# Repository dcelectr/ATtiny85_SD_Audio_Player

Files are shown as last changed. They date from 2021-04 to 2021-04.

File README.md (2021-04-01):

# ATtiny85_SD_Audio_Player
Based on [Simple SD Audio Player](http://elm-chan.org/works/sd8p/report.html)
High voltage serial programer is needed to set the RSTDISBL fuse for the ATiny SD Audio Player (Stereo, OSC, and Mono-HR versions).
You may used the [ProMini HVSP](https://github.com/dcelectr/ProMini_HVSP/tree/main)

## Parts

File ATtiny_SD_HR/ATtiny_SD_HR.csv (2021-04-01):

Reference | Quantity | Value | Footprint | Datasheet | P/N
C1 C3 | 2 | 100nF | Capacitor_SMD:C_0805_2012Metric_Pad1.18x1.45mm_HandSolder | ~ | 885012207011
C2 C5 | 2 | 100uF | Capacitor_Tantalum_SMD:CP_EIA-3216-10_Kemet-I_Pad1.58x1.35mm_HandSolder | ~ | TPSC107M016R0200
J1 | 1 | Micro_SD_Card_Det | User_PCB_Libraries:Molex_1051620001_KiCad | https://www.hirose.com/product/en/download_file/key_name/DM3/category/Catalog/doc_file_id/49662/?item_id=195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 | 1051620001
J2 J3 J4 | 3 | Conn_01x02_Male | Connector_PinHeader_2.00mm:PinHeader_1x02_P2.00mm_Vertical | ~ | N/A
R1 R2 | 2 | 4.53K | Resistor_SMD:R_0805_2012Metric_Pad1.20x1.40mm_HandSolder | ~ | ERJ-6ENF4531V
U1 | 1 | AP2112K-3.3 | Package_TO_SOT_SMD:SOT-23-5 | https://www.diodes.com/assets/Datasheets/AP2112.pdf | NCP603SN330T1G
U2 | 1 | ATtiny85-20SU | Package_SO:SOIC-8W_5.3x5.3mm_P1.27mm | http://ww1.microchip.com/downloads/en/DeviceDoc/atmel-2586-avr-8-bit-microcontroller-attiny25-attiny45-attiny85_datasheet.pdf | ATTINY85-20SUR

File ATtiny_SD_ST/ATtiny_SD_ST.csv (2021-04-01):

Reference | Quantity | Value | Footprint | Datasheet | P/N
C1 C3 | 2 | 100nF | Capacitor_SMD:C_0805_2012Metric_Pad1.18x1.45mm_HandSolder | ~ | 885012207011
C2 C4 C5 | 3 | 100uF | Capacitor_Tantalum_SMD:CP_EIA-3216-10_Kemet-I_Pad1.58x1.35mm_HandSolder | ~ | TPSC107M016R0200
J1 | 1 | Micro_SD_Card_Det | User_PCB_Libraries:Molex_1051620001_KiCad | https://www.hirose.com/product/en/download_file/key_name/DM3/category/Catalog/doc_file_id/49662/?item_id=195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 | 1051620001
J2 J3 | 2 | Conn_01x02_Male | Connector_PinHeader_2.00mm:PinHeader_1x02_P2.00mm_Vertical | ~ | N/A
J4 | 1 | Conn_01x04_Male | Connector_PinHeader_2.00mm:PinHeader_1x04_P2.00mm_Vertical | ~ | N/A
R1 | 1 | 4.7K | Resistor_SMD:R_0805_2012Metric_Pad1.20x1.40mm_HandSolder | ~ | ERJ-6ENF4701V
U1 | 1 | AP2112K-3.3 | Package_TO_SOT_SMD:SOT-23-5 | https://www.diodes.com/assets/Datasheets/AP2112.pdf | NCP603SN330T1G
U2 | 1 | ATtiny85-20SU | Package_SO:SOIC-8W_5.3x5.3mm_P1.27mm | http://ww1.microchip.com/downloads/en/DeviceDoc/atmel-2586-avr-8-bit-microcontroller-attiny25-attiny45-attiny85_datasheet.pdf | ATTINY85-20SUR

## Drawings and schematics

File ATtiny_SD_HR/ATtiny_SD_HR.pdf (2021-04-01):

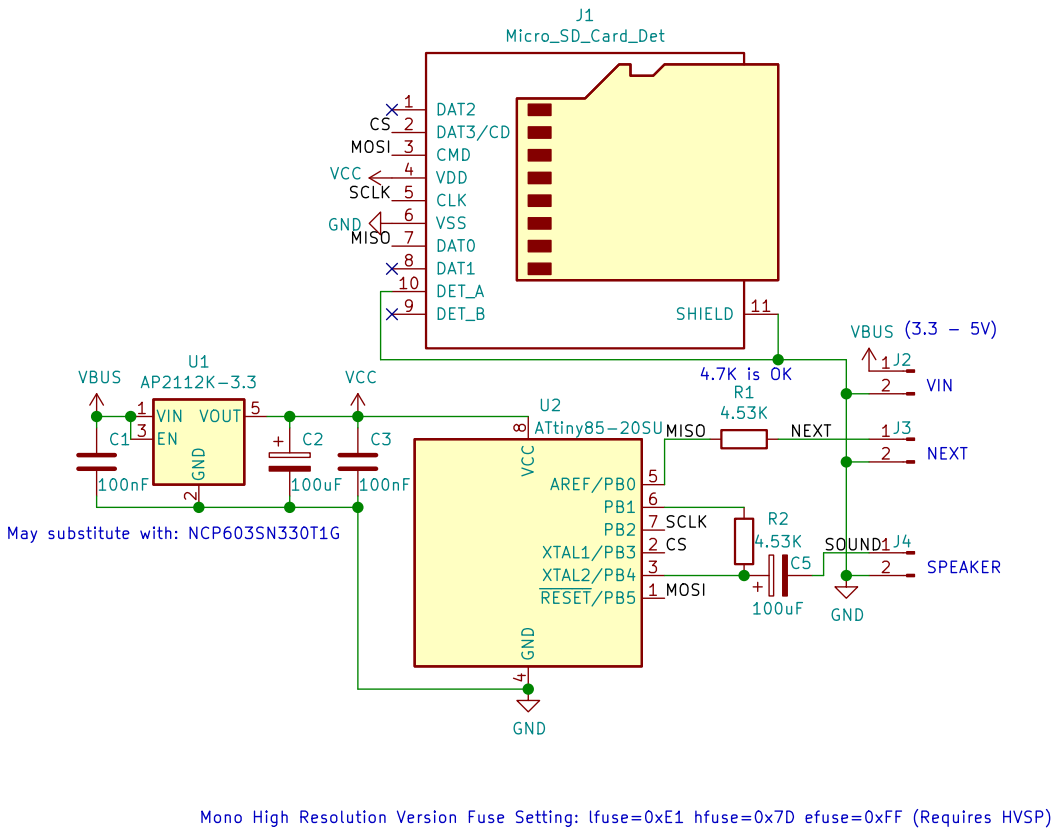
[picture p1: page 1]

2 EN 3 VOUT 5 U1 AP2112K-3.3 RESET/PB5 1 XTAL1/PB3 2 XTAL2/PB4 3 GND

File: ATtiny_SD_HR.sch Sheet: / GND

Mono High Resolution Version Fuse Setting: lfuse=0xE1 hfuse=0x7D efuse=0xFF (Requires HVSP)

Id: 1/1 Title: ATtiny85 SD Audio Player Mono High Resolution

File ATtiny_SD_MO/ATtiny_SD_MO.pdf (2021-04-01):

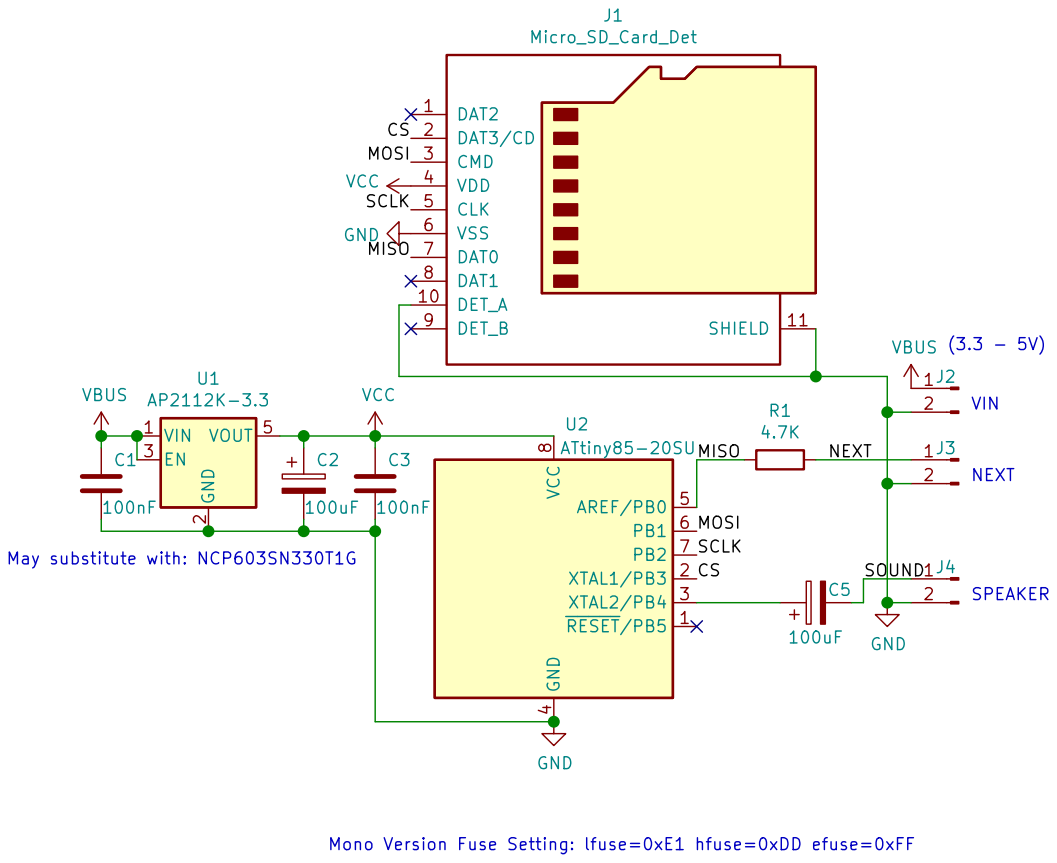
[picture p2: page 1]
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

NEXT May substitute with: NCP603SN330T1G

File: ATtiny_SD_MO.sch Sheet: / GND

Id: 1/1 Title: ATtiny85 SD Audio Player Mono

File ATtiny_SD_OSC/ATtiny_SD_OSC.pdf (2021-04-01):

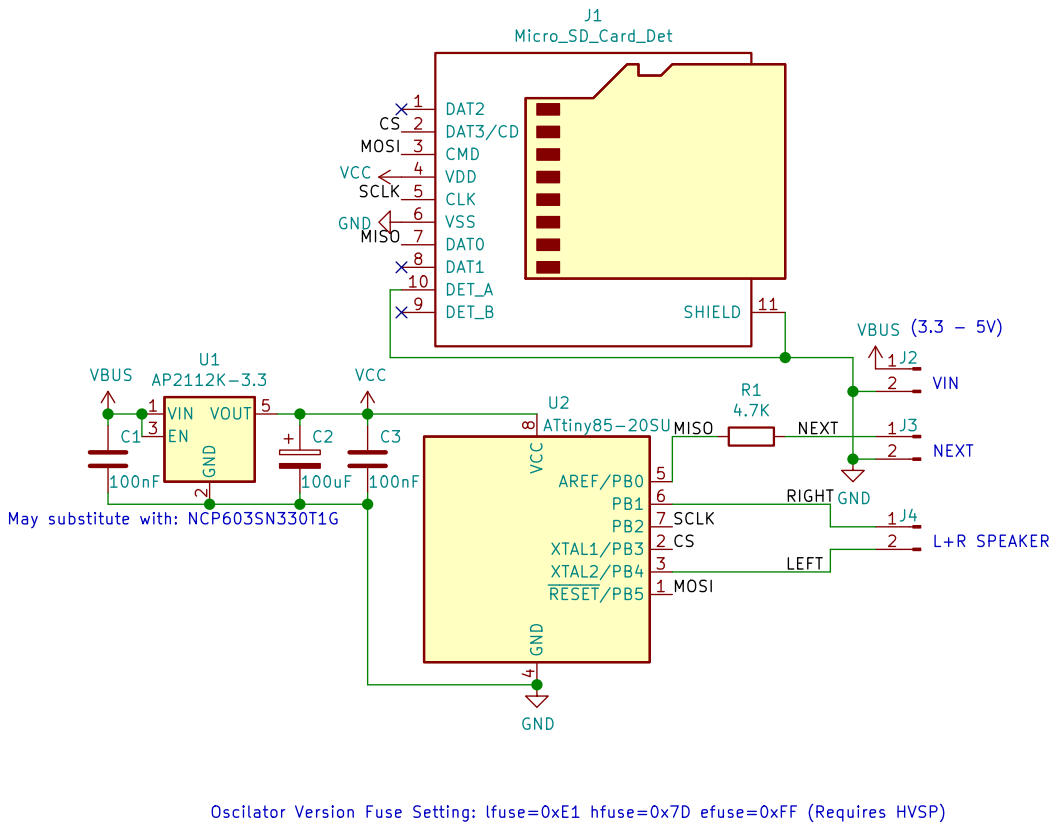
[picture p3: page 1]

LEFT RIGHT SCLKCS MISO

(3.3 - 5V) NEXT VIN Oscilator Version Fuse Setting: lfuse=0xE1 hfuse=0x7D efuse=0xFF (Requires HVSP)

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

File: ATtiny_SD_OSC.sch Sheet: / GND

Id: 1/1 Title: ATtiny85 SD Audio Player OSC

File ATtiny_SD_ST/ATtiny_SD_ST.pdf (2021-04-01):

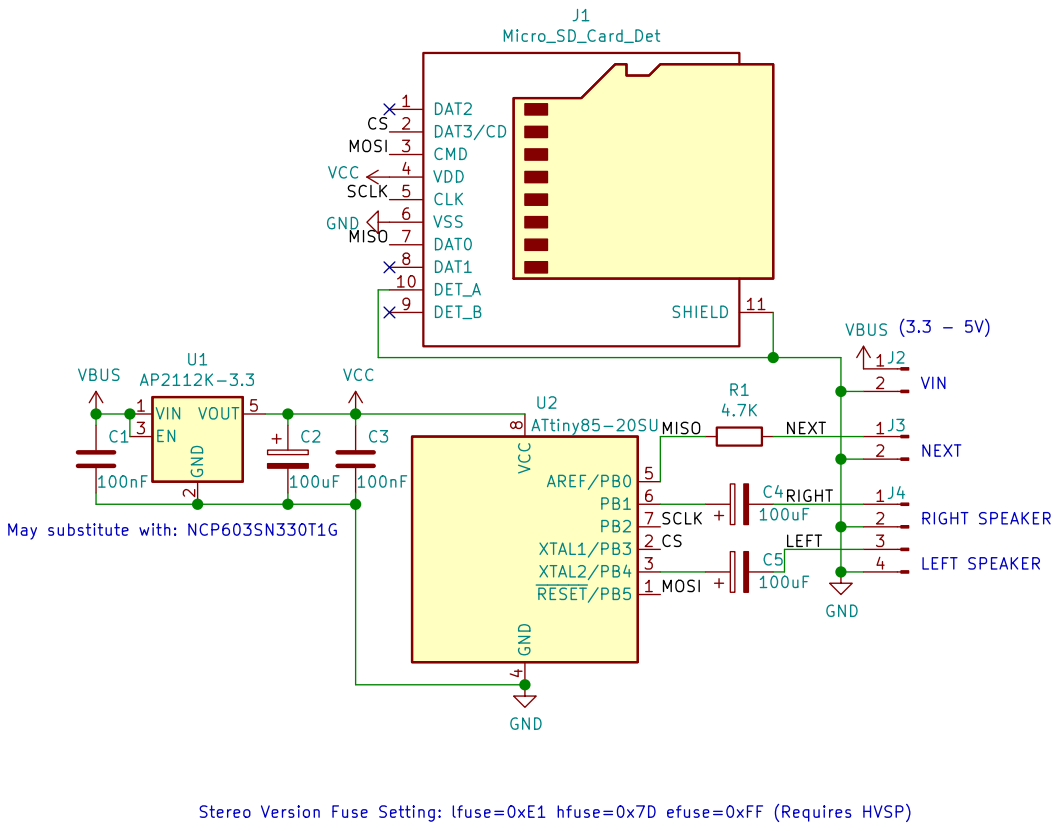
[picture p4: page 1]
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

File: ATtiny_SD_ST.sch Sheet: / GND

Id: 1/1 Title: ATtiny85 SD Audio Player Stereo

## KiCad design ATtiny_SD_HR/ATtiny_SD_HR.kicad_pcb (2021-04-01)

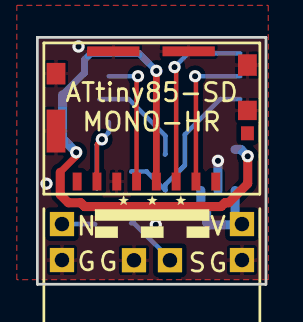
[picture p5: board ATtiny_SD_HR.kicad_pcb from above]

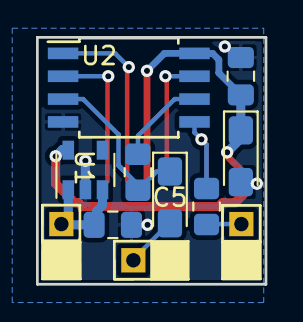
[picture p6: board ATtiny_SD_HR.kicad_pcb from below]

Board: 2 copper layers, 12.7 x 13.7 mm, 12 parts (11 on the bottom side), 11 nets.

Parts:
C1, C3: 100nF; C_0805_2012Metric_Pad1.18x1.45mm_HandSolder
C2: 150uF; CP_EIA-3216-10_Kemet-I_Pad1.58x1.35mm_HandSolder
C5: 100uF; CP_EIA-3216-10_Kemet-I_Pad1.58x1.35mm_HandSolder
J1: Micro_SD_Card_Det; Molex_1051620001_KiCad
J2, J3, J4: Conn_01x02_Male; PinHeader_1x02_P2.00mm_Vertical
R1: 4.7K; R_0805_2012Metric_Pad1.20x1.40mm_HandSolder
R2: 4.5K; R_0805_2012Metric_Pad1.20x1.40mm_HandSolder
U1: AP2112K-3.3; SOT-23-5
U2: ATtiny85-20SU; SOIC-8W_5.3x5.3mm_P1.27mm

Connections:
/CS: J1.2, U2.2
/MISO: J1.7, R1.2, U2.5
/MOSI: J1.3, U2.1
/NEXT: J3.1, R1.1
/SCLK: J1.5, U2.7
/SOUND: C5.2, J4.1
GND: C1.2, C2.2, C3.2, J1.6, J1.10, J1.11, J2.2, J3.2, J4.2, U1.2, U2.4
unnamed: C5.1, R2.2, U2.3
unnamed: R2.1, U2.6
VBUS: C1.1, J2.1, U1.1, U1.3
VCC: C2.1, C3.1, J1.4, U1.5, U2.8

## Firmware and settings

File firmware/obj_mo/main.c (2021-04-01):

/*----------------------------------------------------------------------------/
/  8-pin SD audio player R0.05d                    (C)ChaN, 2011              /
/-----------------------------------------------------------------------------/
/ This project, program codes and circuit diagrams, is opened under license
/ policy of following trems.
/
/  Copyright (C) 2010, ChaN, all right reserved.
/
/ * This project is a free software and there is NO WARRANTY.
/ * No restriction on use. You can use, modify and redistribute it for
/   personal, non-profit or commercial use UNDER YOUR RESPONSIBILITY.
/ * Redistributions of source code must retain the above copyright notice.
/
/----------------------------------------------------------------------------*/

#include <avr/io.h>
#include <avr/interrupt.h>
#include <avr/sleep.h>
#include <avr/wdt.h>
#include <string.h>
#include "pff.h"
#include "xitoa.h"

#ifndef MODE
#error Wrong make file.
#endif
#if   MODE == 0	/* Single output */
FUSES = {0xE1, 0xDD, 0xFF};	/* Fuse bytes for mono: Low, High and Extended */
#else			/* Dual output */
FUSES = {0xE1, 0x7D, 0xFF};	/* Fuse bytes for stereo and mono-HR: Low, High and Extended (*HVS mode only*) */
#endif
/* This is the fuse settings of this project. The fuse data will be included
in the output hex file with program code. However some old flash programmers
cannot load the fuse bits from hex file. If it is the case, remove this line
and use these values to program the fuse bits. */


#define FCC(c1,c2,c3,c4)	(((DWORD)c4<<24)+((DWORD)c3<<16)+((WORD)c2<<8)+(BYTE)c1)	/* FourCC */

void delay_us (WORD);	/* Defined in asmfunc.S */



/*---------------------------------------------------------*/
/* Work Area                                               */
/*---------------------------------------------------------*/

volatile BYTE FifoRi, FifoWi, FifoCt;	/* FIFO controls */

BYTE Buff[256];		/* Wave output FIFO */

FATFS Fs;			/* File system object */
DIR Dir;			/* Directory object */
FILINFO Fno;		/* File information */

WORD rb;			/* Return value. Put this here to avoid avr-gcc's bug */



/*---------------------------------------------------------*/

static
DWORD load_header (void)	/* 0:Invalid format, 1:I/O error, >=1024:Number of samples */
{
	DWORD sz, f;
	BYTE b, al = 0;


	if (pf_read(Buff, 12, &rb)) return 1;	/* Load file header (12 bytes) */

	if (rb != 12 || LD_DWORD(Buff+8) != FCC('W','A','V','E')) return 0;

	for (;;) {
		wdt_reset();
		pf_read(Buff, 8, &rb);			/* Get Chunk ID and size */
		if (rb != 8) return 0;
		sz = LD_DWORD(&Buff[4]);		/* Chunk size */

		switch (LD_DWORD(&Buff[0])) {	/* Switch by chunk ID */
		case FCC('f','m','t',' ') :					/* 'fmt ' chunk */
			if (sz & 1) sz++;						/* Align chunk size */
			if (sz > 100 || sz < 16) return 0;		/* Check chunk size */
			pf_read(Buff, sz, &rb);					/* Get content */
			if (rb != sz) return 0;
			if (Buff[0] != 1) return 0;				/* Check coding type (LPCM) */
			b = Buff[2];
			if (b != 1 && b != 2) return 0;			/* Check channels (1/2) */
			GPIOR0 = al = b;						/* Save channel flag */
			b = Buff[14];
			if (b != 8 && b != 16) return 0;		/* Check resolution (8/16 bit) */
			GPIOR0 |= b;							/* Save resolution flag */
			if (b & 16) al <<= 1;
			f = LD_DWORD(&Buff[4]);					/* Check sampling freqency (8k-48k) */
			if (f < 8000 || f > 48000) return 4;
			OCR0A = (BYTE)(F_CPU / 8 / f) - 1;		/* Set sampling interval */
			break;

		case FCC('d','a','t','a') :		/* 'data' chunk */
			if (!al) return 0;							/* Check if format is valid */
			if (sz < 1024 || (sz & (al - 1))) return 0;	/* Check size */
			if (Fs.fptr & (al - 1)) return 0;			/* Check word alignment */
			return sz;									/* Start to play */

		case FCC('D','I','S','P') :		/* 'DISP' chunk */
		case FCC('L','I','S','T') :		/* 'LIST' chunk */
		case FCC('f','a','c','t') :		/* 'fact' chunk */
			if (sz & 1) sz++;				/* Align chunk size */
			pf_lseek(Fs.fptr + sz);			/* Skip this chunk */
			break;

		default :						/* Unknown chunk */
			return 0;
		}
	}

	return 0;
}



static
void ramp (
	int dir		/* 0:Ramp-down, 1:Ramp-up */
)
{
#if MODE != 3
	BYTE v, d, n;


	if (dir) {
		v = 0; d = 1;
	} else {
		v = 128; d = (BYTE)-1;
	}

	n = 128;
	do {
		v += d;
		OCR1A = v; OCR1B = v;
		delay_us(100);
	} while (--n);
#else
	dir = dir ? 128 : 0;
	OCR1A = (BYTE)dir; OCR1B = (BYTE)dir;
#endif
}



static
FRESULT play (
	const char *dir,	/* Directory */
	const char *fn		/* File */
)
{
	DWORD sz;
	FRESULT res;
	BYTE sw;
	WORD btr;


	wdt_reset();

	xsprintf((char*)Buff, PSTR("%s/%s"), dir, fn);
	res = pf_open((char*)Buff);		/* Open sound file */
	if (res == FR_OK) {
		sz = load_header();			/* Check file format and ready to play */
		if (sz < 1024) return 255;	/* Cannot play this file */

		FifoCt = 0; FifoRi = 0; FifoWi = 0;	/* Reset audio FIFO */

		if (!TCCR1) {				/* Enable audio out if not enabled */
			PLLCSR = 0b00000110;	/* Select PLL clock for TC1.ck */
			GTCCR =  0b01100000;	/* Enable OC1B as PWM */
			TCCR1 = MODE ? 0b01100001 : 0b00000001;	/* Start TC1 and enable OC1A as PWM if needed */
			TCCR0A = 0b00000010;	/* Statr TC0 as interval timer at 2MHz */
			TCCR0B = 0b00000010;
			TIMSK = _BV(OCIE0A);
			ramp(1);
		}

		pf_read(0, 512 - (Fs.fptr % 512), &rb);	/* Snip sector unaligned part */
		sz -= rb;
		sw = 1;	/* Button status flag */
		do {	/* Data transfer loop */
			wdt_reset();

			btr = (sz > 1024) ? 1024 : (WORD)sz;/* A chunk of audio data */
			res = pf_read(0, btr, &rb);	/* Forward the data into audio FIFO */
			if (rb != 1024) break;		/* Break on error or end of data */
			sz -= rb;					/* Decrease data counter */

			sw <<= 1;					/* Break on button down */
		} while ((PINB & 1) || ++sw != 1);
	}

	while (FifoCt) ;			/* Wait for audio FIFO empty */
	OCR1A = 128; OCR1B = 128;	/* Return output to center level */

	return res;
}



static
void delay500 (void)
{
	wdt_reset();

	TCCR0B = 0; TCCR0A = 0;	/* Stop TC0 */

	if (TCCR1) {	/* Stop TC1 if enabled */
		ramp(0);
		TCCR1 = 0; GTCCR = 0;
	}

	WDTCR = _BV(WDE) | _BV(WDIE) | 0b101;	/* Set WDT to interrupt mode in timeout of 0.5s */
	set_sleep_mode(SLEEP_MODE_PWR_DOWN);	/* Enter power down mode */
	sleep_mode();

	wdt_reset();
	WDTCR = _BV(WDE) | 0b110;				/* Set WDT to reset mode in timeout of 1s */
}


EMPTY_INTERRUPT(WDT_vect);



/*-----------------------------------------------------------------------*/
/* Main                                                                  */

int main (void)
{
	FRESULT res;
	char *dir;
	BYTE org_osc = OSCCAL;


	MCUSR = 0;
	WDTCR = _BV(WDE) | 0b110;	/* Enable WDT reset in timeout of 1s */

	PORTB = 0b101001;		/* Initialize port: - - H L H L L P */
	DDRB  = 0b111110;

	sei();

	for (;;) {
		if (pf_mount(&Fs) == FR_OK) {	/* Initialize FS */
			wdt_reset();
			Buff[0] = 0;
			if (!pf_open("osccal")) pf_read(Buff, 1, &rb);	/* Adjust frequency */
			OSCCAL = org_osc + Buff[0];

			res = pf_opendir(&Dir, dir = "wav");	/* Open sound file directory */
			if (res == FR_NO_PATH)
				res = pf_opendir(&Dir, dir = "");	/* Open root directory */

			while (res == FR_OK) {				/* Repeat in the dir */
				res = pf_readdir(&Dir, 0);			/* Rewind dir */
				while (res == FR_OK) {				/* Play all wav files in the dir */
					wdt_reset();
					res = pf_readdir(&Dir, &Fno);		/* Get a dir entry */
					if (res || !Fno.fname[0]) break;	/* Break on error or end of dir */
					if (!(Fno.fattrib & (AM_DIR|AM_HID)) && strstr(Fno.fname, ".WAV"))
						res = play(dir, Fno.fname);		/* Play file */
				}
			}
		}
		delay500();			/* Delay 500ms in low power sleep mode */
	}
}
